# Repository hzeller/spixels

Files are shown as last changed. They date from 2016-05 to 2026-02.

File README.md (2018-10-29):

SPI Pixels - Control 16 LED strips at once
==========================================
http://spixels.org/

Parallely feeding 16 SPI LED strips with a Raspberry Pi.

This is the hardware and library separated out of the [FlaschenTaschen] project
to be used independently.

This provides a Raspberry Pi Adapter to connect up to 16 SPI-type LED strips
(such as **APA102**, **WS2801**, **LPD6803**), that are fed by the Raspberry Pi
in parallel for fast update rates.

The C++ library can be found in [include/](./include) and
[lib/](./lib), with examples in the, you guessed it,
[examples/](./examples) directory.

If you want to use the library in your own projects, just add it as a
sub-module to your project:

```
git submodule add https://github.com/hzeller/spixels
```

You now have a subdirectory `spixels/` in your project. See
the [Makefile](./examples/Makefile) in the examples/ directory as a
template how to use it with your project.

You find the board in the [hardware/](./hardware/pi-adapter-16) directory
(including Gerbers and OshPark link).

The adpater is compatible with any Raspberry Pi with 40 GPIO pins, such as the
Pi 1 B+, Pi 2 or Pi 3.

Of course, you can use the MultiSPI feature to send data to other simple
devices.
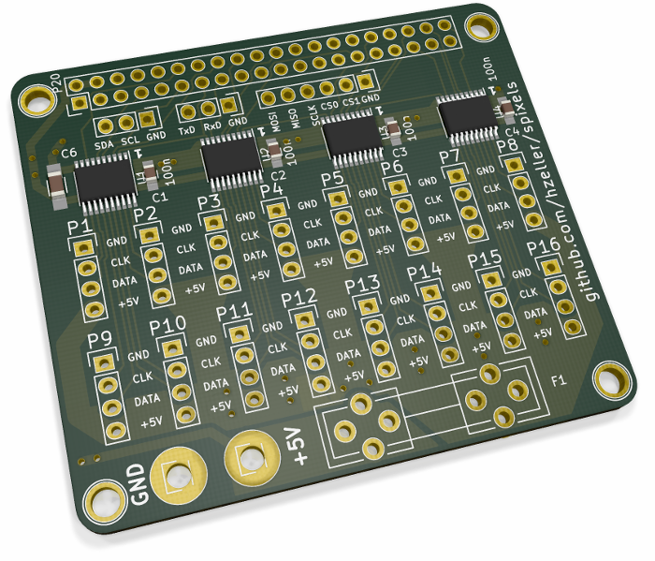
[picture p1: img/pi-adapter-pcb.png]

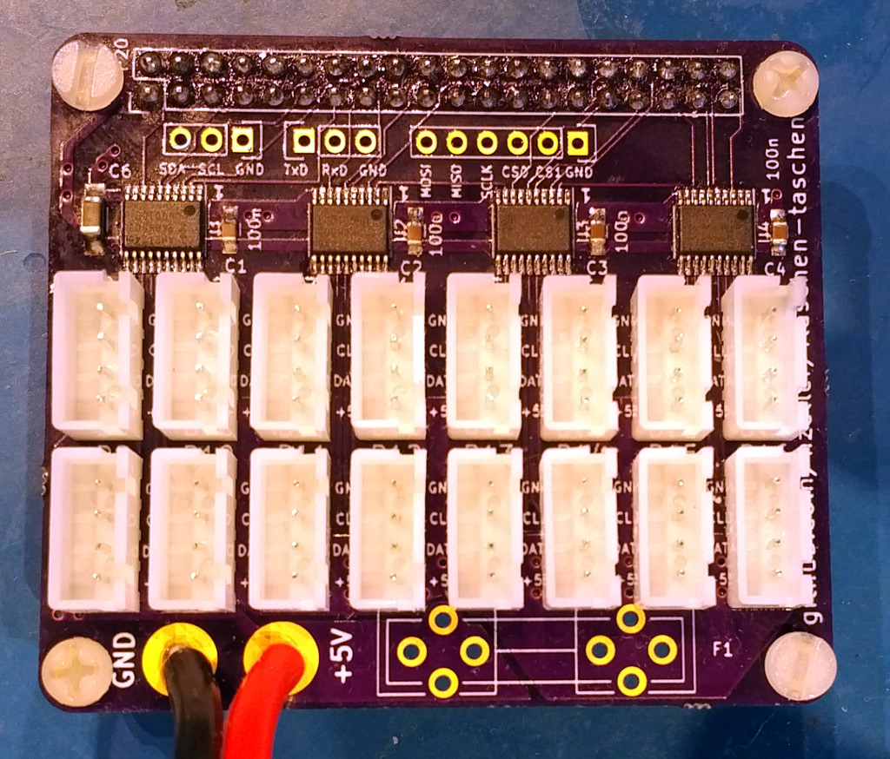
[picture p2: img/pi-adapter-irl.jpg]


A single APA102 strip connected to the board:

[Spixels simple](http://youtu.be/HAbR64yrjUk)

This is used in the [FlaschenTaschen] project, in which only 9 of the 16
connectors are used, one for each 'crate column'. The update rate with
WS2801 reaches 160fps!.

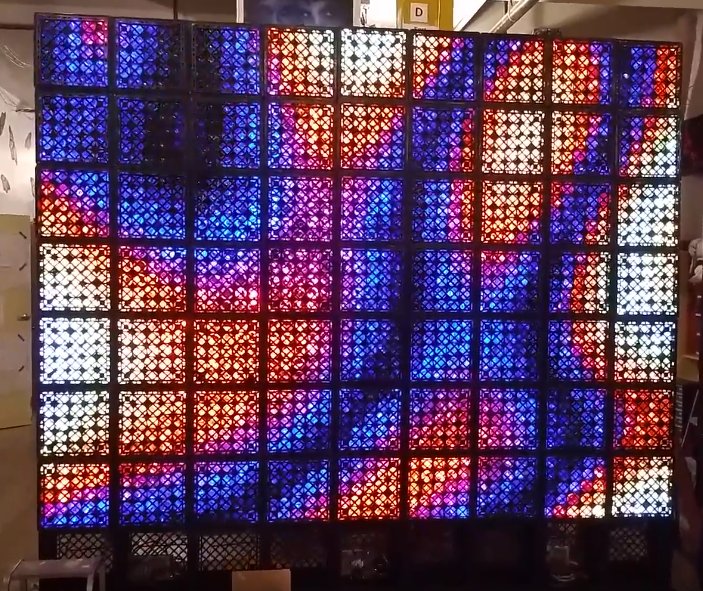
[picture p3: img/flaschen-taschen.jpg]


[FlaschenTaschen]: https://github.com/hzeller/flaschen-taschen
[run-vid]: ./img/spixels-video.jpg

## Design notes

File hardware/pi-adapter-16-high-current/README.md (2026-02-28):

# High Current Spixel

Spixel board that allows two separate power supply inputs for 8 strands,
and heavy copper pour to drive current to these. The backside allows to
add additional power-carrying bars.

**NOTE** while wiring up the LED strips: the connections are inside out with
the negative power connection at the center of the board, followed by
clock, data, and positive connection towards the long edges of the board (this
is different from the wiring in the [low current board](../pi-adapter-16)).

The power rails are named `LED-` and `LED+` as this would be the typical
polarity configuration, but it also allows to wire them up with inverted
polarity if the LED strips need `[-,data,clock,+]`,

For correct operation, you need to connect whatever is `GND` on the LEDs with
`GND` on the Pi on the PI/LEDd jumper square on the left. In the common case
in which `LED-` is negative, it is just a straight wire accross.

It is also possible to power the Raspberry Pi from the top power rail
(as long as they are 5V) if you also connect the 5V from the rail with the
5V input of the Pi at that same jumper block.

The connection to the power rails and the LED strips need a lot of heat to
solder, in particular if you have 70μm (2oz) copper on there.
An inductive soldering iron is highly recommended.

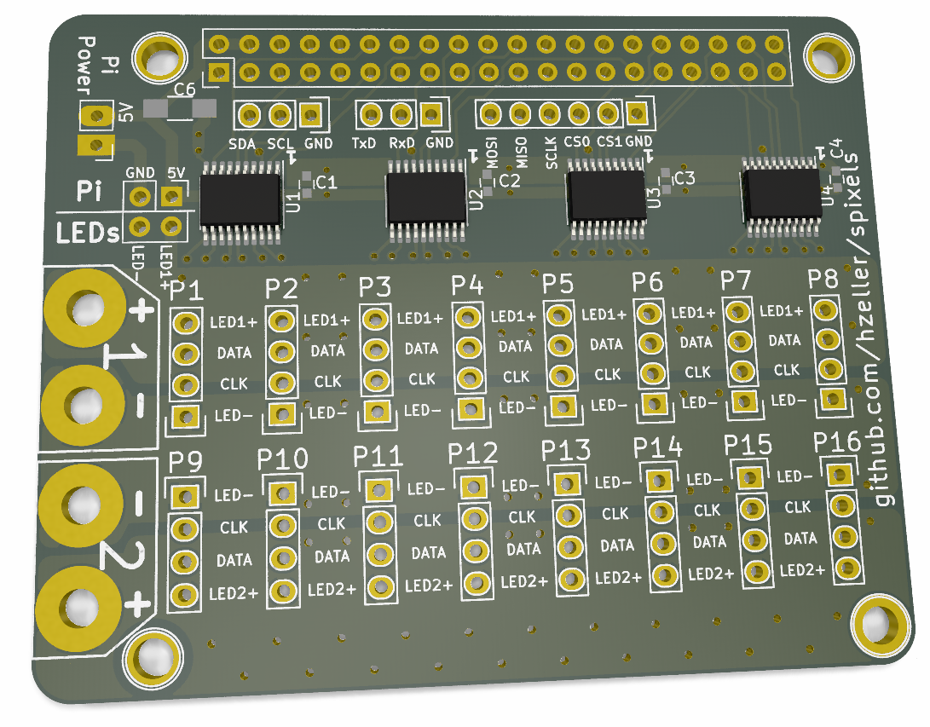
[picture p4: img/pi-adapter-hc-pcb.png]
PCB-render

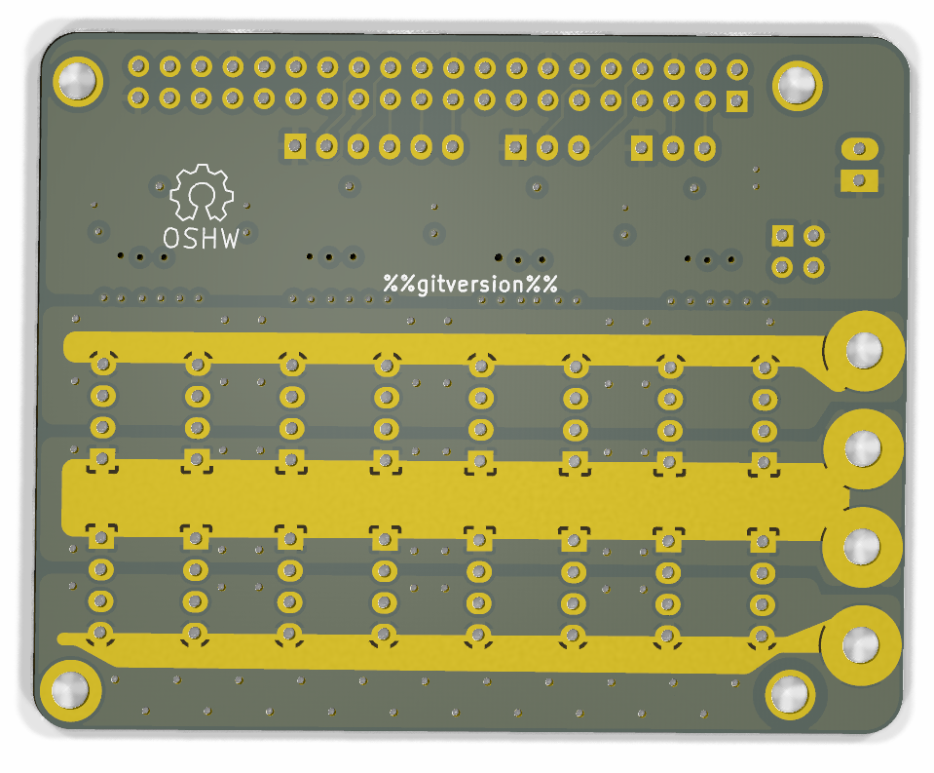
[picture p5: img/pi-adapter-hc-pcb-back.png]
backside


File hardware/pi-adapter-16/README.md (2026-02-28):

16 LED strip Raspberry Pi Adapter
=================================

Adapter to connect up to 16 SPI-type LED strips (e.g. WS2801, LPD6803 or APA102).
The software to control these SPI outputs can be found in the `MultiSPI` class
in this project.

The output pins contain GND, CLK and Data. Also, 5V is given which can power
shorter LED strips or is useful for active termination of longer wires.

Pinout of each of the connectors:

GND | CLK | DATA | +5V
---:|:---:|:----:|:---

(GND is pointing towards the Rasbperry Pi GPIO header).

### Features

* 16 data outputs for LED strips including GND and 5V. All outputs receive data
  in parallel.
* Input power (5V) operates level shifter as well as the Raspberry Pi; no
  separate USB supply needed.
* Fused 5V outputs on connectors to prevent accidents.
* The pins of the I²C, UART and system-SPI busses (including both CS-lines)
  of the Raspberry Pi are not occupied by the data lines. They are broken out
  and allow connecting other common peripherals.

The CLK is shared, but each connector gets a dedicated buffered signal.

The 5V output, accessible on each of the 16 connectors, is fused, so that
accidental shorts when messing with the LED strip wires in the field do not
cause harm.

If you don't need 5V at all (using an external power supply), don't add a fuse.
For smaller power use (e.g. active termination), use a 1A fuse.
The outputs are beefy enough that they even could support a couple of
shorter 5V LED strips directly, in that case use up to 20A fuse. However,
generally it is advisable to separately power the strips;
20A only powers 300 LEDs or so.

If there is no fuse, then the 5V connectors are floating, but note that all
5V pins on that rail are connected with each other: if you use multiple
external power supplies, only connect GND, not 5V to prevent balancing currents.

### BOM
|Count | Type | Package | Info
|-----:|---|---|---
| 4 | 74HCT245 | TSSOP-20 | HCT or AHCT _not_ HC.
| 4 | 100nF ceramic capacitor | 0805 | One per HCT245
| 1 | 22µF ceramic capacitor, 6.3V| 1206 | Stabilizing Pi Power
| 1 | 20x2 female pin socket | 0.1" raster  | to connect to Pi GPIO
| 16 | 4x1 pin header | 0.1" raster  | to connect to LED strips
| 1 | Fuse holder | for 20mm fuse| Optional (see text)

### Making board

Get a reasonable current version of kicad (or use the shell.nix) and call

```
make
```

This will create the gerbers in `pi-adapter-fab/` and also produces
a `pi-adapter-fab.zip`, ready to be sent to a fab.

It is also [shared on OSH Park][oshpark-pcb] (not affiliated).

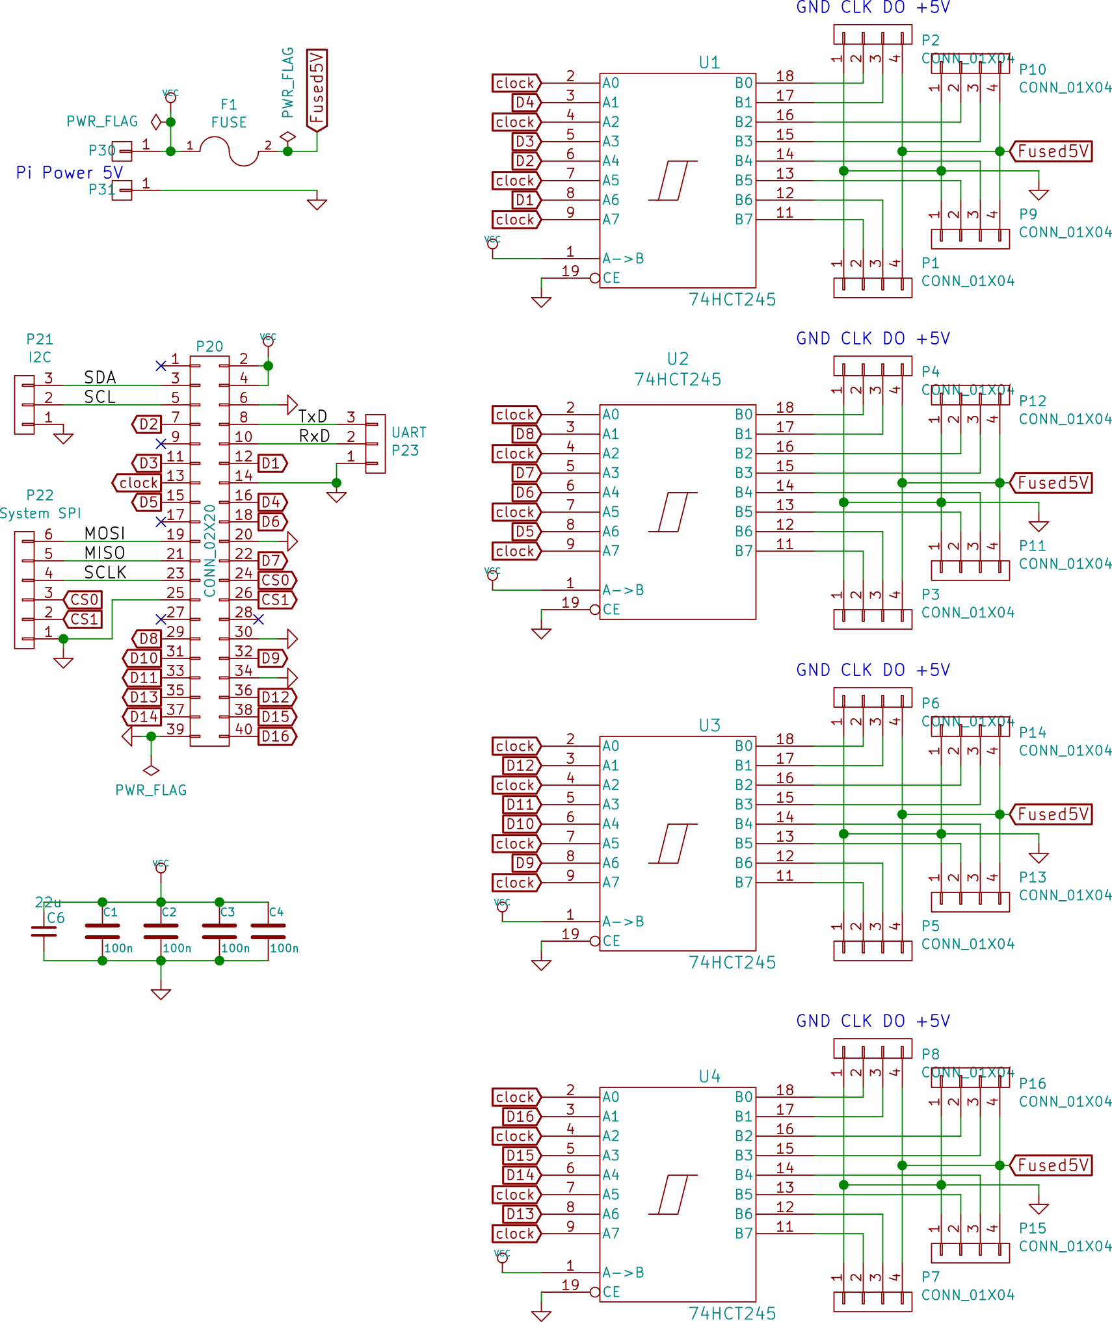
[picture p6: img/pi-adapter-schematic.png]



[oshpark-pcb]: https://oshpark.com/shared_projects/BTdhLFc3

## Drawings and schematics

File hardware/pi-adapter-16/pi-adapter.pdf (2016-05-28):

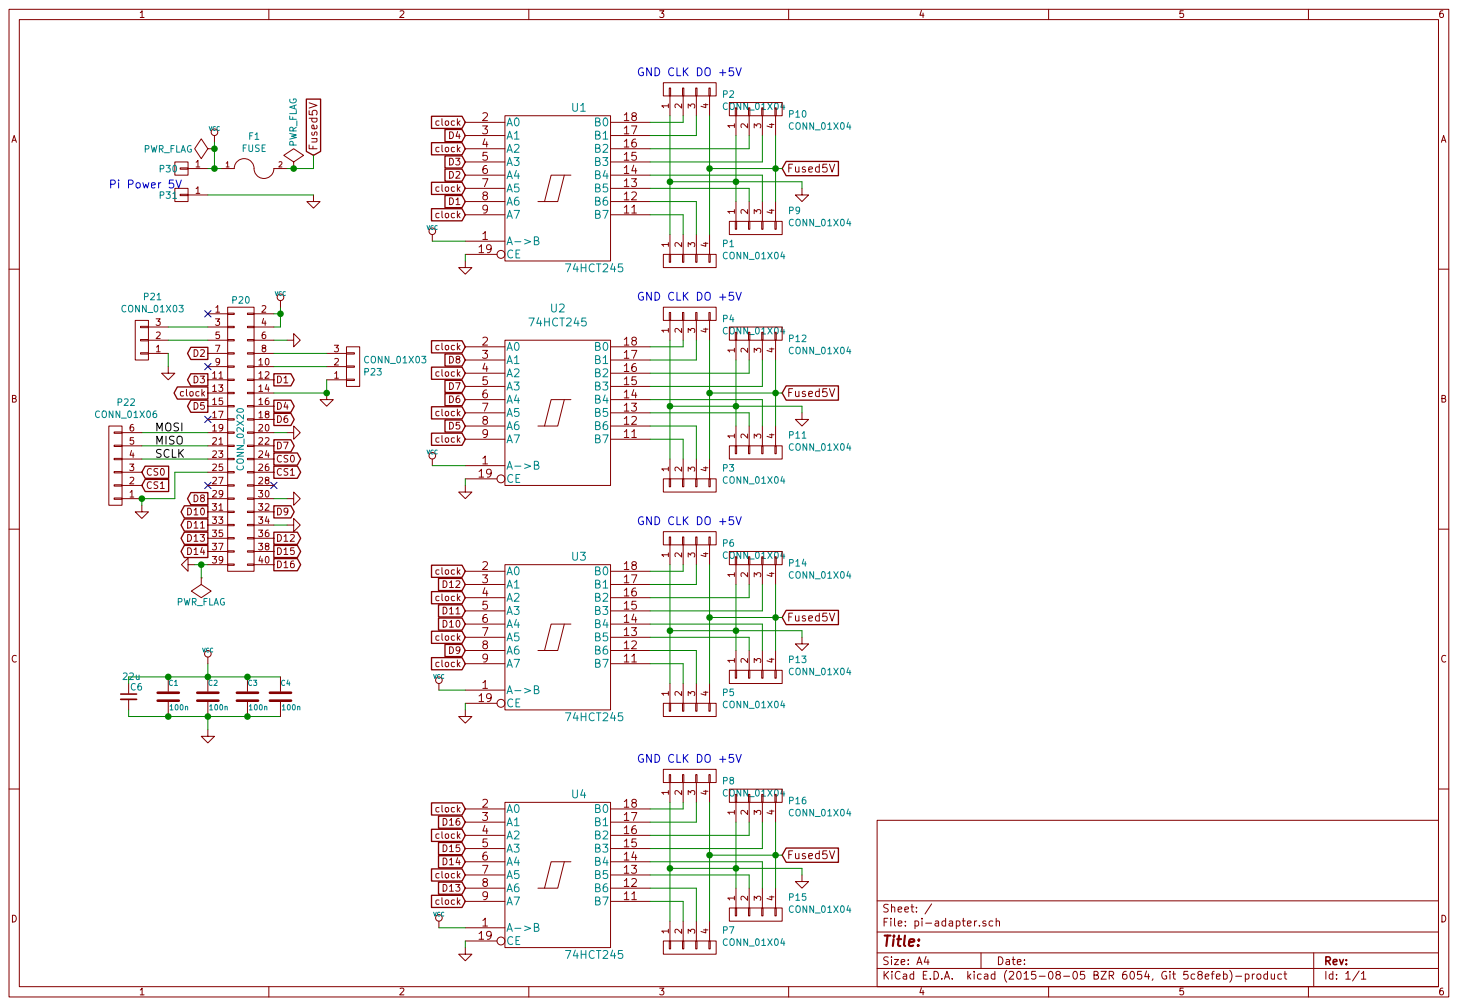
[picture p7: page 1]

MISO | 21

23 | 24
25 | | 26
27 | 28

File: pi-adapter.sch Sheet: /

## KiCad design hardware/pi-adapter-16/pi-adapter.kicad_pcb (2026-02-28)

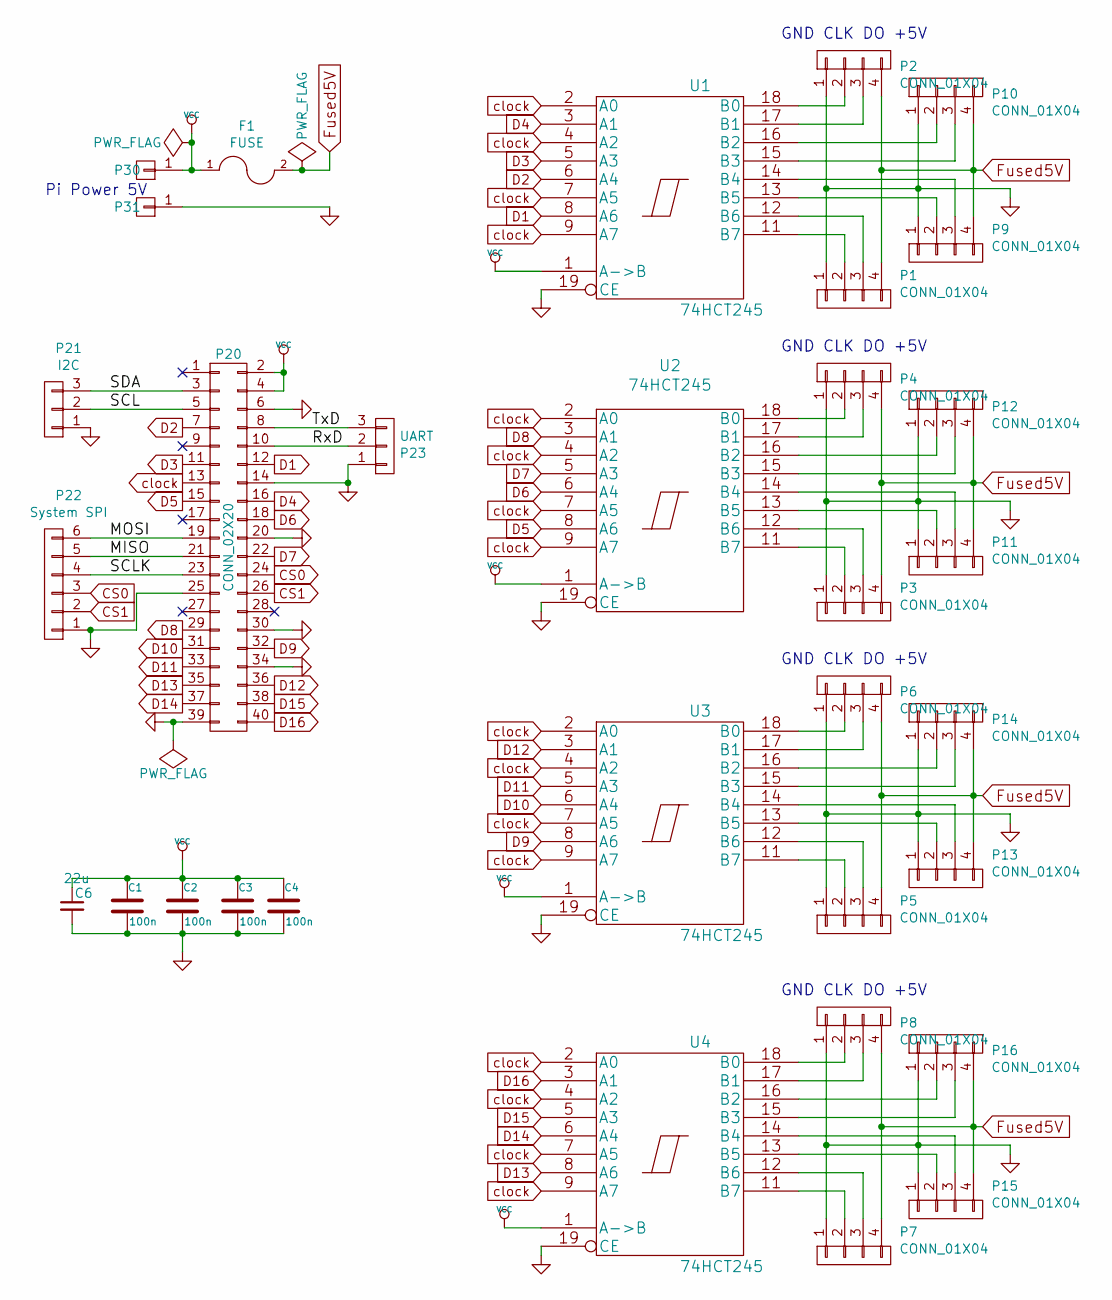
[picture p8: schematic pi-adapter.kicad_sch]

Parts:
C1, C2, C3, C4: 100n; C_0805_HandSoldering
C6: 22u; C_1206_HandSoldering
F1: FUSE; Fuseholder5x20_horiz_open_universal_Type-III
P1, P2, P3, P4, P5, P6, P7, P8, P9, P10, P11, P12, P13, P14, P15, P16: CONN_01X04; Pin_Header_Straight_1x04
P20: CONN_02X20; Pin_Header_Straight_2x20
P21: I2C; Pin_Header_Straight_1x03
P22: System SPI; Pin_Header_Straight_1x06
P23: UART; Pin_Header_Straight_1x03
P30: +5V; Pin_Header_Straight_1x01
P31: GND; Pin_Header_Straight_1x01
U1, U2, U3, U4: 74HCT245; TSSOP-20_4.4x6.5mm_Pitch0.65mm

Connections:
/MISO: P20.21, P22.5
/MOSI: P20.19, P22.6
/SCLK: P20.23, P22.4
CS0: P20.24, P22.3
CS1: P20.26, P22.2
D1: P20.12, U1.8 (A6)
D2: P20.7, U1.6 (A4)
D3: P20.11, U1.5 (A3)
D4: P20.16, U1.3 (A1)
D5: P20.15, U2.8 (A6)
D6: P20.18, U2.6 (A4)
D7: P20.22, U2.5 (A3)
D8: P20.29, U2.3 (A1)
D9: P20.32, U3.8 (A6)
D10: P20.31, U3.6 (A4)
D11: P20.33, U3.5 (A3)
D12: P20.36, U3.3 (A1)
D13: P20.35, U4.8 (A6)
D14: P20.37, U4.6 (A4)
D15: P20.38, U4.5 (A3)
D16: P20.40, U4.3 (A1)
Fused5V: F1.2, P1.4, P2.4, P3.4, P4.4, P5.4, P6.4, P7.4, P8.4, P9.4, P10.4, P11.4, P12.4, P13.4, P14.4, P15.4, P16.4
GND: C1.2, C2.2, C3.2, C4.2, C6.2, P1.1, P2.1, P3.1, P4.1, P5.1, P6.1, P7.1, P8.1, P9.1, P10.1, P11.1, P12.1, P13.1, P14.1, P15.1, P16.1, P20.6, P20.14, P20.20, P20.25, P20.30, P20.34, P20.39, P21.1, P22.1, P23.1, P31.1, U1.10 (GND), U1.19 (CE), U2.10 (GND), U2.19 (CE), U3.10 (GND), U3.19 (CE), U4.10 (GND), U4.19 (CE)
unnamed: P1.2, U1.11 (B7)
unnamed: P1.3, U1.12 (B6)
unnamed: P2.2, U1.18 (B0)
unnamed: P2.3, U1.17 (B1)
unnamed: P3.2, U2.11 (B7)
unnamed: P3.3, U2.12 (B6)
unnamed: P4.2, U2.18 (B0)
unnamed: P4.3, U2.17 (B1)
unnamed: P5.2, U3.11 (B7)
unnamed: P5.3, U3.12 (B6)
unnamed: P6.2, U3.18 (B0)
unnamed: P6.3, U3.17 (B1)
unnamed: P7.2, U4.11 (B7)
unnamed: P7.3, U4.12 (B6)
unnamed: P8.2, U4.18 (B0)
unnamed: P8.3, U4.17 (B1)
unnamed: P9.2, U1.13 (B5)
unnamed: P9.3, U1.14 (B4)
unnamed: P10.2, U1.16 (B2)
unnamed: P10.3, U1.15 (B3)
unnamed: P11.2, U2.13 (B5)
unnamed: P11.3, U2.14 (B4)
unnamed: P12.2, U2.16 (B2)
unnamed: P12.3, U2.15 (B3)
unnamed: P13.2, U3.13 (B5)
unnamed: P13.3, U3.14 (B4)
unnamed: P14.2, U3.16 (B2)
unnamed: P14.3, U3.15 (B3)
unnamed: P15.2, U4.13 (B5)
unnamed: P15.3, U4.14 (B4)
unnamed: P16.2, U4.16 (B2)
unnamed: P16.3, U4.15 (B3)
unnamed: P20.3, P21.3
unnamed: P20.5, P21.2
unnamed: P20.8, P23.3
unnamed: P20.10, P23.2
VCC: C1.1, C2.1, C3.1, C4.1, C6.1, F1.1, P20.2, P20.4, P30.1, U1.1 (A->B), U1.20 (VCC), U2.1 (A->B), U2.20 (VCC), U3.1 (A->B), U3.20 (VCC), U4.1 (A->B), U4.20 (VCC)
clock: P20.13, U1.2 (A0), U1.4 (A2), U1.7 (A5), U1.9 (A7), U2.2 (A0), U2.4 (A2), U2.7 (A5), U2.9 (A7), U3.2 (A0), U3.4 (A2), U3.7 (A5), U3.9 (A7), U4.2 (A0), U4.4 (A2), U4.7 (A5), U4.9 (A7)

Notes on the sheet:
GND CLK DO +5V
Pi Power 5V

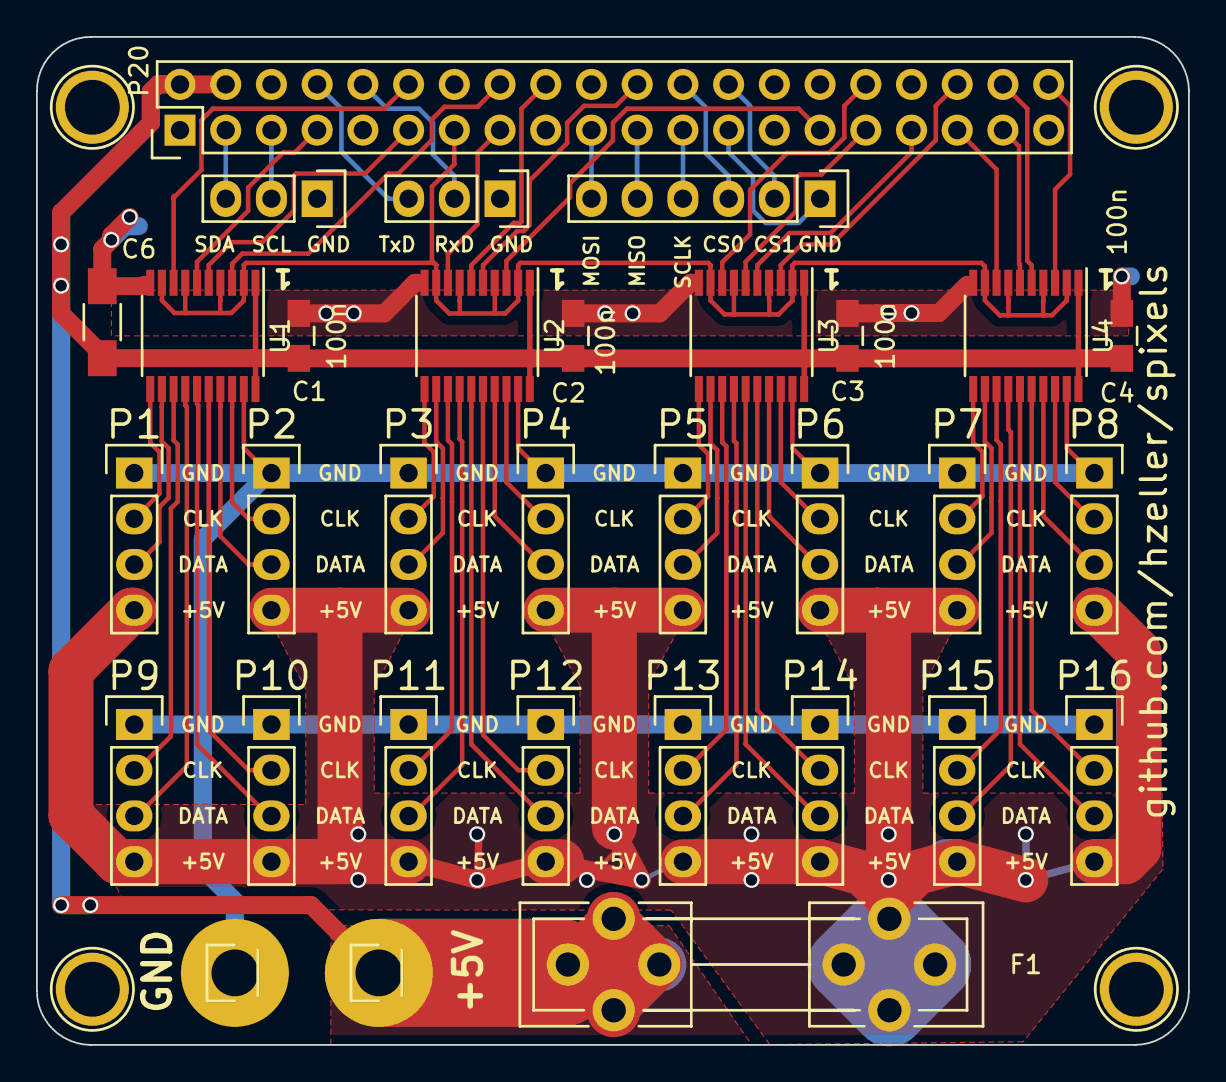
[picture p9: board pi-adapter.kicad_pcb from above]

Board: 2 copper layers, 64.0 x 56.0 mm, 36 parts (0 on the bottom side), 61 nets.

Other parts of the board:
P40, P40#2, P41, P43: CONN_01X01; 1pin

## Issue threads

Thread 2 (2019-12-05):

Question RE: Frame rate

mizraith, 2019-12-05:
First off... your documentation is excellent!   Came across your rpi matrix library and am very impressed.

This library, however, is more appropriate for what I am doing (controlling several chains for neopixel type LEDs).

Do you have refresh rate estimations (rpi 2 or rpi 3) depending on chain length?    For instance, can I push 8 chains of 500 pixels and get at least 15fps?

Thank you!!!

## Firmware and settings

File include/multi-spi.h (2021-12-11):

// -*- mode: c++; c-basic-offset: 4; indent-tabs-mode: nil; -*-
// SPI Pixels - Control SPI LED strips (spixels)
// Copyright (C) 2016 Henner Zeller <h.zeller@acm.org>
//
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
#ifndef SPIXELS_MULTI_SPI_H
#define SPIXELS_MULTI_SPI_H

#include <stdint.h>
#include <stddef.h>

namespace spixels {
// MultiSPI outputs multiple SPI streams in parallel on different GPIOs.
// The clock is on a single GPIO-pin. This way, we can transmit 25-ish
// SPI streams in parallel on a Pi with 40 IO pins.
// Current implementation assumes that all streams have the same amount
// of data.
// Also, there is no chip-select at this point (not needed for the LED strips).
//
// This can be used of course of LED strips (see led-strip.h for the API), but
// for all kinds of other SPI data you want to send to multiple devices in
// a fire-and-forget way.
class MultiSPI {
public:
    // Names of the pin-headers on the breakout board.
    enum {
        SPI_CLOCK = 27,

        SPI_P1  = 18,
        SPI_P2  = 23,
        SPI_P3  = 22,
        SPI_P4  =  5,
        SPI_P5  = 12,
        SPI_P6  = 16,
        SPI_P7  = 19,
        SPI_P8  = 21,

        SPI_P9  =  4,
        SPI_P10 = 17,
        SPI_P11 = 24,
        SPI_P12 = 25,
        SPI_P13 =  6,
        SPI_P14 = 13,
        SPI_P15 = 26,
        SPI_P16 = 20,
    };

    // A function that maps the connector number (P1..P16) to the value of
    // the corresponding SPI Pin SPI_P1..SPI_P16 constant.
    static int SPIPinForConnector(int connector);

    virtual ~MultiSPI() {}

    // Register a new data stream for the given GPIO. The SPI data is
    // sent with the common clock and this gpio pin. The gpio must be one
    // of the above SPI_xx constants or the return value of
    // SPIPinForConnector().
    //
    // Note, each channel might receive more bytes because they share the
    // same clock with everyone and it depends on what is the longest requested
    // length.
    // Overlength transmission bytes are all zero.
    virtual bool RegisterDataGPIO(int gpio, size_t serial_byte_size) = 0;

    // Set data byte for given gpio channel at given position in the
    // stream. "pos" needs to be in range [0 .. serial_bytes_per_stream)
    // Data is sent with next Send().
    virtual void SetBufferedByte(int data_gpio, size_t pos, uint8_t data) = 0;

    // Send data for all streams. Wait for completion. After SendBuffers()
    // has been called once, no new GPIOs can be registered.
    virtual void SendBuffers() = 0;
};

// Factory to create a MultiSPI implementation that directly writes to
// GPIO. Unless you use a WS2801 strip, this is typically what you want.
// Advantages:
//   - Fast
// Disadvantages:
//   - Potentially has jitter which is problematic with LED-strips that
//     use a time-component for triggering (WS2801).
// Parameter:
//   "speed_mhz" rough speed in Mhz of the SPI clock. Useful values 1..15
//   Default is 4. Increase if your set-up can do more and you need the
//   speed. Decrease if you see erratic behavior.
MultiSPI *CreateDirectMultiSPI(float speed_mhz = 4,
                               int clock_gpio = MultiSPI::SPI_CLOCK);

// Factory to create a MultiSPI implementation that uses DMA to output.
// Advantages:
//   - Does not use CPU
//   - Jitter does not exceed several 10 usec. Needed for WS2801.
// Disadvantage:
//   - Limited speed (1-2Mhz). Good for WS2801 which can't go faster
//     anyway, but wasting potential with LPD6803 or APA102 that can go
//     much faster.
MultiSPI *CreateDMAMultiSPI(int clock_gpio = MultiSPI::SPI_CLOCK);
}

#endif  // SPIXELS_MULTI_SPI_H

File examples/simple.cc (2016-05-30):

/* -*- mode: c++; c-basic-offset: 4; indent-tabs-mode: nil; -*-
 * Simple example how to use the spixels library
 */

#include "led-strip.h"

#include <unistd.h>  // for usleep()

#define FRAME_RATE 60

using namespace spixels;

int main() {
    // If you are using WS2801, then you need CreateDMAMultiSPI() instead,
    // as these strips are finicky with timings.
    //
    // See include/multi-spi.h
    MultiSPI *spi = CreateDirectMultiSPI();

    // Connect LED strips with 144 LEDs to connector P1 and P2
    // Choose the type of LEDs from the factory name.
    //
    // See include/led-strip.h
    LEDStrip *strip1 = CreateAPA102Strip(spi, MultiSPI::SPI_P1, 144);
    LEDStrip *strip2 = CreateAPA102Strip(spi, MultiSPI::SPI_P2, 144);
    // ... register more strips here. They can be of different types

    for (unsigned int i = 0; /**/; ++i) {
	const int pos = i % strip1->count();
        strip1->SetPixel(pos, 0x000000);   // clear previous pixel.
        strip2->SetPixel(pos, 0x000000);

        // Various ways to set pixels

        // Red Pixel, given as RGB hex value.
        strip1->SetPixel(pos+1, 0xFF0000);

        // Alternative way: A Green pixel, given as RGB-color struct.
        strip1->SetPixel(pos+2, RGBc(0, 255, 0));

        // Alternative way: give values as separate red/green/blue value.
        strip1->SetPixel(pos+3, 0, 0, 255);

        // A Blue pixel on the second strip.
        strip2->SetPixel(pos+1, 0, 0, 255);
    
        spi->SendBuffers();  // Send all pixels out at once.
        usleep(1000000 / FRAME_RATE);
    }

    delete strip1;
    delete strip2;
    delete spi;
}

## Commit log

2016-05-26 o Initial add of board (from flaschen-taschen repository)
    [pi-adapter.kicad_pcb, pi-adapter.sch]
2016-05-28 o Add LED-strip class o Add simple example.
2016-05-29 o Switch to LGPL.
2016-05-30 o Prepare shadow buffer as registered GPIO comes in. Allows to set bits right then, which is what some LEDs need.
2016-05-30 o make PCB picture link to hardware/ page.
2016-05-30 o Provide link to the PCB on OshPark
2016-06-02 o Say where to get board.
2016-06-03 o Use the global brightness settings of APA102 to gain 4 more bits at the bottom. o Switch brightness API to use uint8_t instead of float.
2016-06-04 o Provide a raw linear LEDStrip::SetLinearValue() method with 16-bit resolution of RGB values - so the implementation has the freedom to provide whatever it can do (5 Bit LPD6803, up to 12Bit APA102)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
2016-06-04 o Clarify README about headers provided for system SPI bus. o fix some typos: LDP6803 -> LPD6803
    [multi-spi.h]
2017-04-23 Update silk-screen text to point to spixels github.
    [pi-adapter.kicad_pcb]
2017-04-23 Provide a SPIPinForConnector() to do logical to physical pin-mapping.
2017-04-23 Update PCB rendering.
2017-06-04 Add Schematic image in hardware/README.md
    [pi-adapter.sch]
2018-10-29 Move adapter to separate subdirectory.
    [pi-adapter.kicad_pcb, pi-adapter.sch]
2018-10-29 Prepare for newer KiCAD.
    [pi-adapter.sch]
2018-10-29 Add Gerber zip file for ease of reproduction without KiCAD.
2019-12-23 Support Raspberry Pi 4
    o Update Raspberry Pi detection to detect all kinds of sub-types.
    o consolidate BCM mmap in DMA and GPIO
2021-01-04 Add high-current version.
    [pi-adapter-hc.kicad_pcb, pi-adapter-hc.sch]
2021-01-04 Update to latest version of KiCAD
    [pi-adapter-hc.kicad_pcb, pi-adapter-hc.kicad_sch, pi-adapter-hc.sch]
2021-01-04 Update symbols and packages.
    [pi-adapter-hc.kicad_pcb, pi-adapter-hc.kicad_sch]
2021-01-04 Tweaking some silk-screen positions.
    [pi-adapter-hc.kicad_pcb]
2021-01-05 Separate LED power input for upper and lower bank.
    [pi-adapter-hc.kicad_pcb, pi-adapter-hc.kicad_sch]
2021-01-05 Do all clk/data on an inner layer to utilize thicker outer layers for power.
    [pi-adapter-hc.kicad_pcb]
2021-01-05 Switch on all layers.
    [pi-adapter-hc.kicad_pcb]
2021-01-05 Add second LED minus lug for symmetry.
    [pi-adapter-hc.kicad_pcb, pi-adapter-hc.kicad_sch]
2021-01-05 More clarity in naming LED1+
    [pi-adapter-hc.kicad_pcb]
2021-01-17 Make power connector holes 3mm
    [pi-adapter-hc.kicad_pcb]
2021-01-17 Properly mark AHCT245 logic series.
    [pi-adapter-hc.kicad_pcb, pi-adapter-hc.kicad_sch]
2021-02-26 Tiny: More pleasent routing straight from legs.
    [pi-adapter-hc.kicad_pcb]
2021-12-11 Also allow slower than 1Mhz updates in direct SPI.
    The value is only a rough value anyway, and in faster PIs, even
    1 might be too fast.
    [multi-spi.h]
2026-02-28 Make sure wxwidgets are visible in Python.
    The kicad scripting needs that.
2026-02-28 Re-save with current kicad 9.x
    The last version was saved with a 2020 version.
    [pi-adapter-hc.kicad_pcb, pi-adapter-hc.kicad_sch]
2026-02-28 Re-save with current kicad 9.x
    The last one was done with a 2017-version...
    [pi-adapter.kicad_pcb, pi-adapter.kicad_sch, pi-adapter.sch]
2026-02-28 Remove ancient gerbers.
2026-02-28 shell.nix: get newer kicad + compile fix to gerbv
2026-02-28 Add a readme to the high-current version.
2026-02-28 Add a cave note for LED wiring.

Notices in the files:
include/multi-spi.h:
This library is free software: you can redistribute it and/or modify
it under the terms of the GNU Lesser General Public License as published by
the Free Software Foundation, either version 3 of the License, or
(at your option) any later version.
